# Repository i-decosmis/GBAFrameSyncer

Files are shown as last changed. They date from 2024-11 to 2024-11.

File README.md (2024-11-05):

# GBAFrameSyncer

<div align="center">
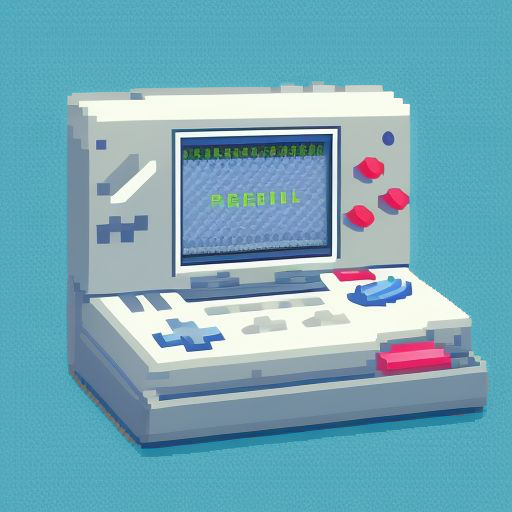
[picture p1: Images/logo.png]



</div>

# Introduction 🎮⏳
This project aims to automate the RNG manipulation process, commonly used on consoles like the Game Boy Advance. This technique, for instance, is used to [obtain shiny Pokémon in games like Pokémon Emerald](https://www.youtube.com/watch?v=pciQkasUJ7g).

Currently, the main issue with this method is that the user must manually press the console buttons to try to reach the desired frame. This process can become lengthy and frustrating, especially when aiming for advanced frames that require long waiting times; if the correct frame isn’t reached, all the waiting time is lost.

With the proposed system, we will physically modify the console to allow Arduino to automatically manage the inputs on the Game Boy Advance, precisely selecting the desired frame based on a preset timer.

# Introduzione 🎮⏳
Questo progetto è volto ad automatizzare il processo di manipolazione dell’RNG, comunemente utilizzato su console come il Game Boy Advance. Questa tecnica, ad esempio, viene sfruttata per [ottenere Pokémon shiny in giochi come Pokémon Smeraldo](https://www.youtube.com/watch?v=pciQkasUJ7g).

Attualmente, il problema principale di questo metodo è che l'utente deve premere manualmente i pulsanti sulla console per cercare di raggiungere il frame desiderato. Questo processo può diventare lungo e frustrante, specialmente quando si punta a frame avanzati che richiedono attese prolungate; se poi non si riesce a selezionare il frame corretto, tutto il tempo trascorso in attesa viene perso.

Con il sistema proposto, modificheremo fisicamente la console per consentire ad Arduino di gestire automaticamente gli input sul Game Boy Advance, selezionando con precisione il frame desiderato in base a un timer preimpostato.

- [English version](Guide/en/README.md)
- [Versione italiana](Guide/it/README.md)

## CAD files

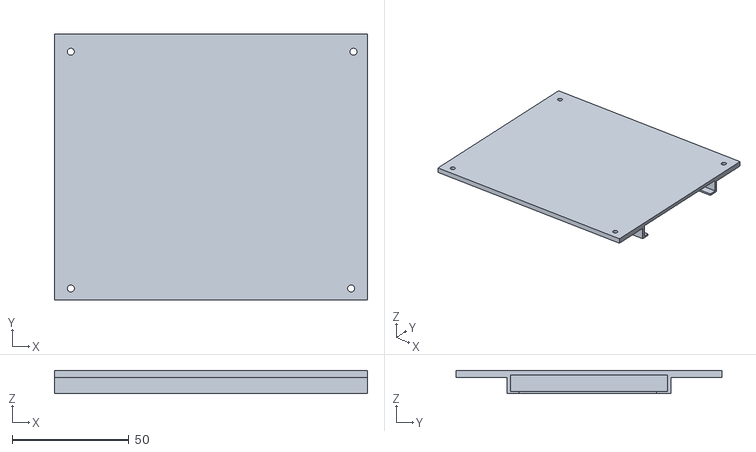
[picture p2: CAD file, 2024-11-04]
3dFiles/lid.stl
134.0 x 114.0 x 10.0

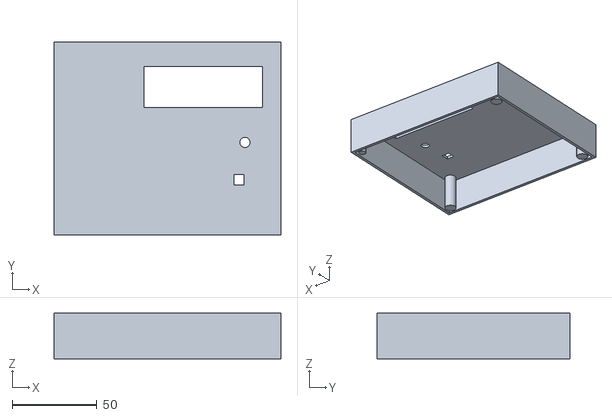
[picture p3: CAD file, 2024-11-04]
3dFiles/case.stl
134.0 x 114.0 x 27.0

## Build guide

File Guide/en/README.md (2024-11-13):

# Responsibility ⚠️
This guide is provided for informational purposes and has been compiled with the utmost care. However, the author accepts no responsibility for any damages, malfunctions, or failures arising from the use of the information contained herein. Users are advised to proceed with caution and use their judgment and expertise. Using this guide is entirely at your own risk.

Following this guide will irreversibly modify the shell.

I recommend following the [video](https://www.youtube.com/watch?v=LYbvFizmgOc) for all the details and using this guide for code references or for an overview of the project.

# System Usage Guide 📝
## Upload the Code 🔄
* Open the Arduino IDE.
* Upload the selected code from the available versions on Arduino (further details below).

## Start 🚀
* Power the system through the USB-C port.
* Connect the system connector to the one installed on the GBA.
* Turn on the system.

## If using the version with LCD display 🖥️
* Adjust brightness by clicking the button.
* Once you’ve selected the desired brightness, hold the button down for more than 2 seconds and then release it.
* Use the potentiometer to set the timer. The potentiometer can increase or decrease the timer by one, ten, one hundred, or one thousand units, depending on the direction of rotation.
* After setting the timer, click the button.
* The GBA will automatically restart after 5 seconds.
* When the set time is up, Arduino will press the A button on the GBA.
* Reset the system by powering off and on Arduino.

## If using the version without LCD display 👀
This version requires a PC.
* Open the `NoDisplayMaxOptimized.ino` code with Arduino IDE.
* In line 2, change the `value` field to set the desired time for the timer.
* Connect Arduino to the GBA via the connector.
* Connect Arduino to the PC.
* If off, turn Arduino on via the button.
* Upload the code to Arduino.
* Arduino will automatically restart the GBA after 5 seconds.
* When the time set in `value` expires, Arduino will press the A button.
* Reset the system by powering off and on Arduino.

## Differences Between the three Code Versions 🆚
Three code versions are available:
* `CompleteCode.ino`: Includes all features, such as the LCD panel and real-time timer progress updates.
* `OptimizedCode.ino`: Includes the LCD panel but is optimized to reduce timer lag by dedicating all resources to timer control, without calculating progress percentage.
* `NoDisplay.ino`: Excludes the LCD display, potentiometer, and button, requiring a PC for use.

`OptimizedCode.ino` and `NoDisplay.ino` provide the same performance.
In `CompleteCode.ino`, performance is still considered, as the remaining percentage is updated only once every 5 seconds, and only if there are at least 10 seconds left, allowing for the best possible precision.

## Considerations about the code
The system must be restarted every time after the timer because I've used the `micros` function that overflow after around 70 minutes. To avoid problems I choos this approach

# Details 🔎
This document does NOT cover RNG manipulation techniques on GBA but presents a system to automate the RNG manipulation process on GBA.  
The goal is to create a system usable without a PC. Refer to the accompanying video for additional step-by-step details.

Here is the translation in English:

# Requirements ✅
* Soldering iron
* Hot glue
* A GBA
* 3D printer
* [Arduino Nano](https://www.amazon.it/dp/B0CWH4P152)
* 4 [optocouplers](https://www.amazon.it/dp/B07X46SYQT)
* [220, 1k, 10k ohm resistors](https://www.amazon.it/dp/B0B8CQ9FYC)
* [Breadboard](https://www.amazon.it/dp/B078HV79XX)
* [100 microF capacitor](https://amzn.eu/d/5ATUCtE)
* [Small electric wires](https://amzn.eu/d/4wbI2sM)
* [Potentiometer](https://www.amazon.it/dp/B09LLVJ4WK)
* [Buttons](https://www.amazon.it/dp/B082DBBPGC)
* [Switches](https://www.amazon.it/dp/B0BTM3WQXN)
* [USB-C connectors](https://www.amazon.it/dp/B0DFPV1V35)
* [USB-C plug](https://www.amazon.it/dp/B0D5PVDJLX)
* [16x02 LCD](https://www.amazon.it/dp/B082166FCL)
* [5-pin connector](https://www.amazon.it/dp/B0C9C2NSYC)
* [Heat shrink tubing](https://amzn.eu/d/3FiaBTP)

# Guide 🧭
## Modifying the GBA 🛠️
In this example, a Game Boy Advance SP is used.
I recommend following the [video](https://www.youtube.com/watch?v=LYbvFizmgOc) for all the details and using this guide for code references or for an overview of the project.

### Step One 1️⃣
Solder thin wires onto the pins highlighted in the image. [Video for details](https://youtu.be/LYbvFizmgOc?si=4nlweEES0AOSoRyo&t=297)

gbamother

### Step Two 2️⃣
Drill the shell.
You can use a pre-modified shell with a hole on the right side.

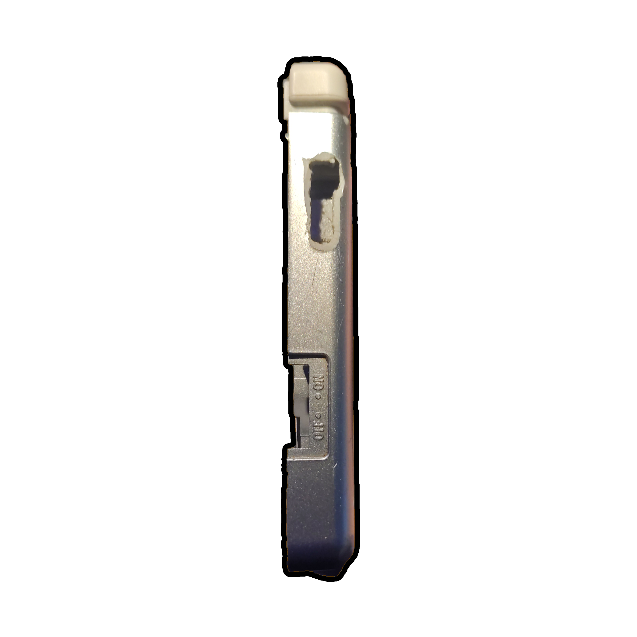
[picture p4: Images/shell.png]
shell


The goal is to guide the newly soldered wires out of the shell. Choose the best spot according to your needs. [Video for details](https://youtu.be/LYbvFizmgOc?si=U2tAdF9u9yge6Rqz&t=344)

### Step Three 3️⃣
Reassemble the GBA SP. [Video for details](https://youtu.be/LYbvFizmgOc?si=co-ZYWx3jPB3q41W&t=473)

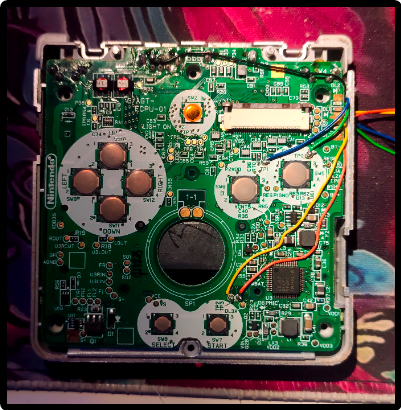
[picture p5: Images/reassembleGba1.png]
reassemble1


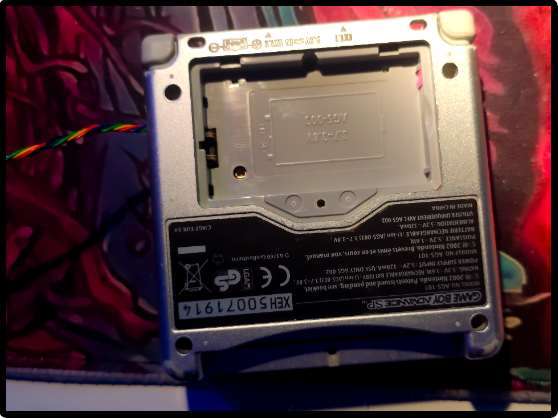
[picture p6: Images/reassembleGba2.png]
reassemble2


## Building the Circuit ⚡
Follow the wiring diagram to create the circuit. [Video for details](https://youtu.be/LYbvFizmgOc?si=nMbl5dTbhvIPqXga&t=812)

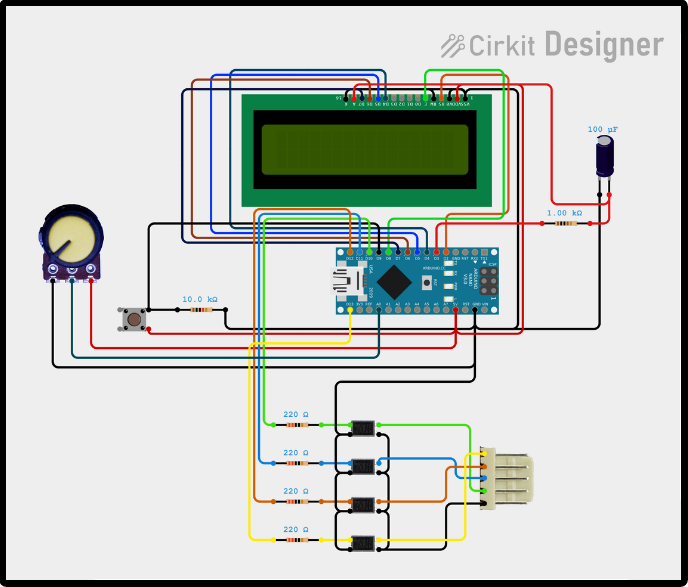
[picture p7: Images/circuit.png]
circuit


A USB-C extension with a button is recommended to interrupt power, allowing Arduino to be powered and reprogrammed even after assembly. [Video for details](https://youtu.be/LYbvFizmgOc?si=zW4mFCezqnHYHnvz&t=1474)
Many portable batteries stop charging if the load is too low, so a resistor in parallel to Arduino is added to enable power from portable batteries. There are more efficient solutions, but this is the simplest and most practical. [Video for details](https://youtu.be/LYbvFizmgOc?si=GJT893XRXDBKK_TV&t=1539)

### Circuit without LCD Display, Potentiometer, and Button ⚡👀
Use the `NoDisplay.ino` code with this wiring diagram.

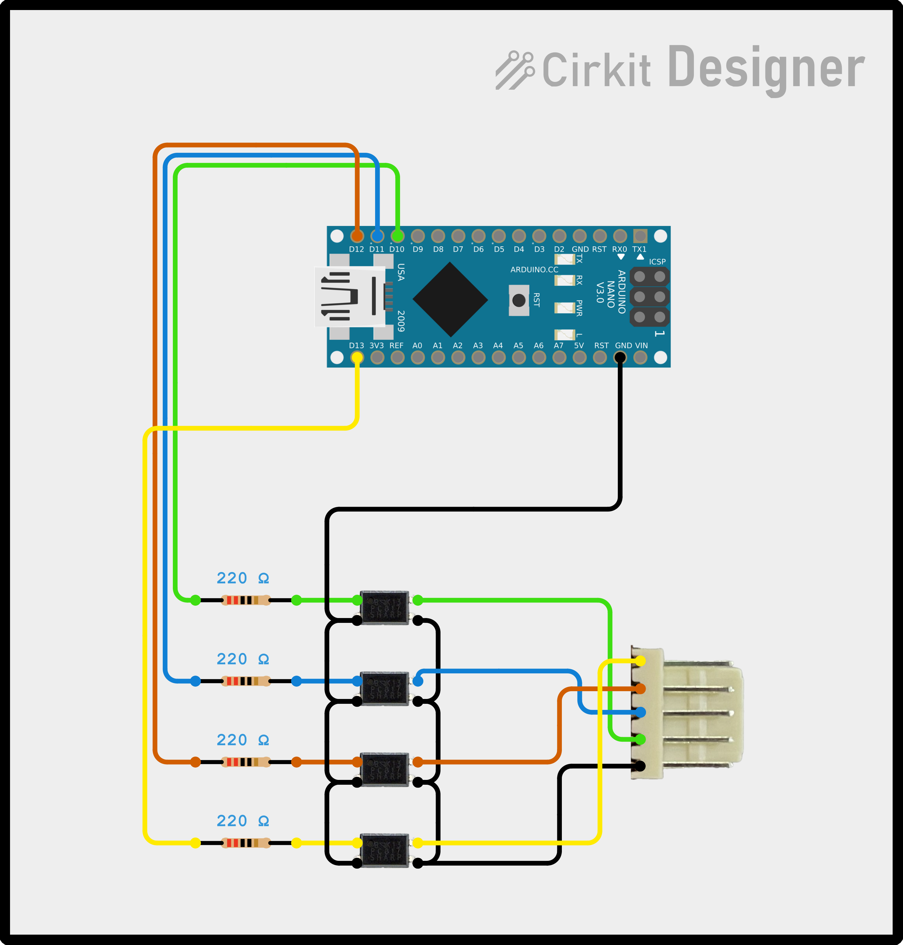
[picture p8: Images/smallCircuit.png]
circuit


## Printing and Assembling the Enclosure 📐
This was my first experience designing and printing an enclosure for a circuit, and there is certainly room for more compactness and optimization.
[This enclosure](../../3dFiles/) is designed for the complete version of the circuit.
Print the 3D file, choose points for drilling holes for the button, input USB-C port, and GBA connector.
Assemble the circuit in the enclosure. [Video for details](https://youtu.be/LYbvFizmgOc?si=2Pv3CYcU8y9FNbQ5)

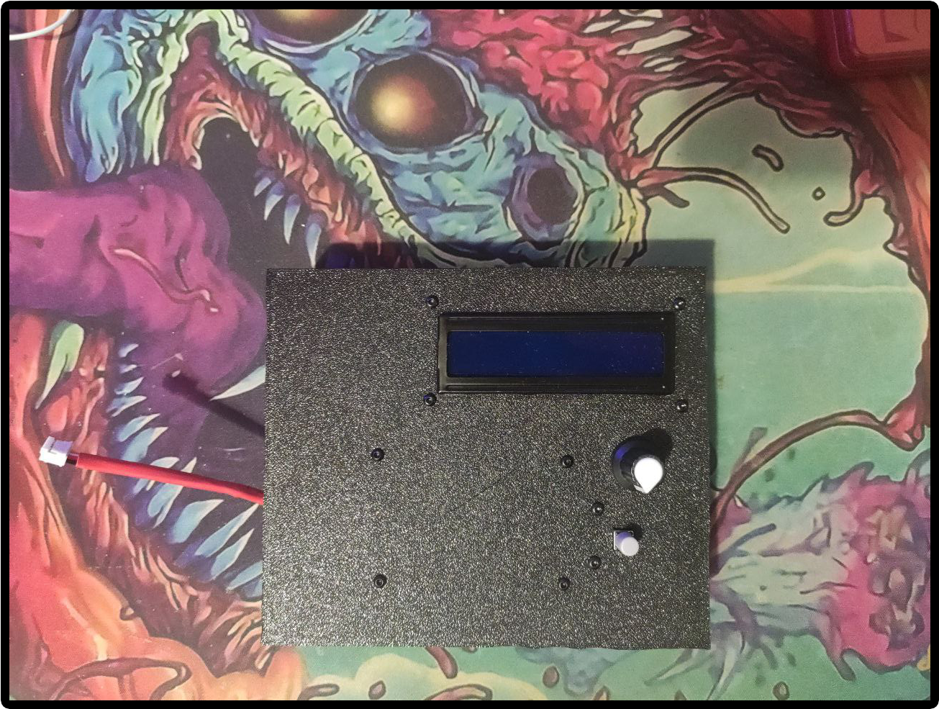
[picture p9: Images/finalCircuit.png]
circuit


There is a section under the cover where a portable battery can be placed. This choice allows the system to be used without a PC or electrical outlet.

circuit

## System Testing 🔬
A system test is available here.

## Physical Error Evaluation 📊
After multiple tests, the maximum number of attempts to calculate physical error in delay was found to be 4. In most cases, no more than 3 attempts were needed.
This error arises from the way Arduino measures time: its ceramic chip is sensitive to temperature changes, causing slight precision fluctuations.
A possible solution could be the use of dedicated timer modules, less affected by temperature.
Also, consider the possible delay of optocouplers and connections.

# Issues 🆘
No issues encountered so far.

# License 🛂
This project is licensed under the **GNU General Public License v3.0**. You are free to use, modify, and distribute this code under the following conditions:

1. **Attribution**: If you use this code as a basis for your project or create derivative works, please credit me by including my name (Ivan De Cosmis) in the project documentation, README, or other relevant materials.

2. **Share Alike**: Any derivative works based on this project must be licensed under GPLv3, ensuring future users benefit from your modifications.

3. **Commercial Use**: If you intend to use this project or derivatives for commercial purposes, contact me to discuss proper attribution and any agreements.

For more details, see the full text of the **GNU General Public License v3.0** [here](https://www.gnu.org/licenses/gpl-3.0.html).

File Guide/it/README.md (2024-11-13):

# Responsabilità ⚠️
Questa guida è fornita a scopo informativo e redatta con la massima cura possibile. Tuttavia, l'autore non si assume alcuna responsabilità per eventuali danni, guasti o malfunzionamenti derivanti dall'uso delle informazioni qui contenute. L'utente è invitato a procedere con cautela e a utilizzare il proprio giudizio e competenza. L'uso di questa guida è interamente a proprio rischio.

Seguire questa guida modifica in modo irreversibile la shell.

Si consiglia di seguire il [video](https://www.youtube.com/watch?v=Go9e5wqC74Q) per tutti i dettagli e usare questa guida per riferimenti al codice o per una visione generale del progetto.

# Guida all'utilizzo del sistema 📝
## Caricare il codice 🔄
* Aprire Arduino IDE.
* Caricare il codice scelto tra le versioni disponibili su Arduino (approfondimenti piú in basso).

## Inizio 🚀
* Alimentare il sistema tramite la porta USB-C.
* Collegare il connettore del sistema a quello installato sul GBA.
* Accendere il sistema.

## Se si utilizza la versione con display LCD 🖥️
* Regolare la luminosità cliccando il pulsante.
* Dopo aver scelto la luminosità preferita, tenere premuto il pulsante per più di 2 secondi e poi rilasciarlo.
* Usare il potenziometro per impostare il timer. Il potenziometro può variare il tempo aggiungendo o sottraendo al timer una, dieci, cento o mille unità, a seconda della rotazione verso destra o sinistra.
* Dopo aver impostato il timer, cliccare il pulsante.
* Dopo 5 secondi il GBA si riavvierà automaticamente.
* Al termine del tempo impostato, Arduino premerà il tasto A sul GBA.
* Resetta il sistema accendendo e spegnendo Arduino.

## Se si utilizza la versione senza display LCD 👀
Questa versione richiede l'uso del PC.
* Aprire il codice `NoDisplayMaxOptimized.ino` con Arduino IDE.
* Alla riga 2, modificare il valore di `value` con il tempo desiderato per il timer.
* Collegare Arduino al GBA tramite il connettore.
* Collegare Arduino al PC.
* Accendere Arduino tramite il pulsante, se spento.
* Caricare il codice su Arduino.
* Dopo 5 secondi Arduino riavvierà automaticamente il GBA.
* Al termine del tempo impostato tramite `value`, Arduino premerà il tasto A.
* Resetta il sistema accendendo e spegnendo Arduino.

## Considerazioni sul codice
Il sistema deve essere riavviato ogni volta dopo il timer perché ho utilizzato la funzione `micros` che va in overflow dopo circa 70 minuti. Per evitare problemi, ho scelto questo approccio.

## Differenze tra le tre versioni di codice 🆚
Sono disponibili tre versioni del codice:
* `CompleteCode.ino`: Include tutte le funzionalità, ovvero il pannello LCD e l'aggiornamento in tempo reale della percentuale di avanzamento del timer.
* `OptimizedCode.ino`: Include il pannello LCD, ma è ottimizzato per ridurre gli sfasamenti del timer, poiché non calcola la percentuale di avanzamento e dedica tutte le risorse al controllo del timer.
* `NoDisplay.ino`: Esclude il display LCD, il potenziometro e il pulsante, richiedendo un PC per l'uso.

`OptimizedCode.ino` e `NoDisplay.ino` offrono le stesse prestazioni.
Ecco una versione rivista:
Nel file `CompleteCode.ino` le prestazioni sono comunque considerate, poiché l'aggiornamento della percentuale rimanente viene calcolato solo una volta ogni 5 secondi, e solo se mancano almeno 10 secondi al termine, permettendo di essere più precisi possibile.

# Dettagli 🔎
In questo documento NON verranno illustrate le tecniche di manipolazione RNG su GBA, ma verrà presentato un sistema per automatizzare il processo di manipolazione RNG su GBA. 
L'obiettivo è ottenere un sistema utilizzabile senza PC. Si consiglia di consultare il video di accompagnamento per ulteriori dettagli sui passaggi.

# Requisiti ✅
* Saldatore
* Colla a caldo
* Un GBA
* Stampante 3D
* [Arduino Nano](https://www.amazon.it/dp/B0CWH4P152)
* 4 [fotoaccoppiatori](https://www.amazon.it/dp/B07X46SYQT)
* [Resistori da 220, 1k, 10k ohm](https://www.amazon.it/dp/B0B8CQ9FYC)
* [Breadboard](https://www.amazon.it/dp/B078HV79XX)
* [Condensatore da 100 microF](https://amzn.eu/d/5ATUCtE)
* [Piccoli fili elettrici](https://amzn.eu/d/4wbI2sM)
* [Potenziometro](https://www.amazon.it/dp/B09LLVJ4WK)
* [Pulsanti](https://www.amazon.it/dp/B082DBBPGC)
* [Interruttori](https://www.amazon.it/dp/B0BTM3WQXN)
* [Connettori USB-C](https://www.amazon.it/dp/B0DFPV1V35)
* [Plug USB-C](https://www.amazon.it/dp/B0D5PVDJLX)
* [LCD 16x02](https://www.amazon.it/dp/B082166FCL)
* [Connettore a 5 pin](https://www.amazon.it/dp/B0C9C2NSYC)
* [Guaina termorestringente](https://amzn.eu/d/3FiaBTP)

# Guida 🧭
## Modifica del GBA 🛠️
In questo esempio, viene utilizzato un Game Boy Advance SP.
Si consiglia di seguire il [video](https://www.youtube.com/watch?v=Go9e5wqC74Q) per tutti i dettagli e usare questa guida per riferimenti al codice o per una visione generale del progetto.

### Primo Passo 1️⃣
Saldare dei fili sottili sui pin evidenziati nell'immagine. [Video per dettagli](https://youtu.be/Go9e5wqC74Q?si=0ailfBb1nve0NTEq&t=297)

gbamother

### Secondo Passo 2️⃣
Forare la shell.
È possibile utilizzare una shell già modificata, con un foro sul lato destro.

shell

L'obiettivo è far uscire i fili appena saldati dalla shell. È possibile scegliere il punto migliore in base alle proprie esigenze. [Video per dettagli](https://youtu.be/Go9e5wqC74Q?si=EwM6Wy2F0S_5Iixp&t=343)

### Terzo Passo 3️⃣
Riassemblare il GBA SP. [Video per dettagli](https://youtu.be/Go9e5wqC74Q?si=ZEf_0g8SJ7sQub_D&t=473)

reassemble1

reassemble2

## Creazione del circuito ⚡
Seguire lo schema elettrico per creare il circuito. [Video per dettagli](https://youtu.be/Go9e5wqC74Q?si=ReuIE5ckI4RUfrOY&t=811)

circuit

È consigliato l'uso di un'estensione USB-C con un pulsante per interrompere l'alimentazione, permettendo di alimentare e riprogrammare Arduino anche dopo l'assemblaggio. [Video per dettagli](https://youtu.be/Go9e5wqC74Q?si=RNg4reDLDHr8Mhwt&t=1474)
Molte batterie portatili smettono di caricare se il carico è troppo basso; per questo motivo è inserita una resistenza in parallelo ad Arduino, consentendo l’alimentazione anche da batterie portatili. Esistono soluzioni più efficienti, ma questa è risultata la più immediata e pratica. [Video per dettagli](https://youtu.be/Go9e5wqC74Q?si=IZFsZYNZBOl73R__&t=1535)

### Circuito senza display LCD, potenziometro e pulsante ⚡👀
Utilizzare il codice `NoDisplay.ino` con questo schema.

circuit

## Stampa e assemblaggio della scocca 📐
Questa è stata la mia prima esperienza nella progettazione e stampa di una scocca per un circuito, e c'è sicuramente margine per una maggiore compattezza e ottimizzazione.
[Questa scocca](../../3dFiles/) è progettata per la versione completa del circuito.
Stampare il file 3D, scegliere i punti in cui praticare i fori per il pulsante, la presa USB-C di ingresso e il connettore per il GBA.
Assemblare il circuito nella scocca. [Video per dettagli](https://youtu.be/Go9e5wqC74Q?si=8puFOmgHlYpe24ta&t=1650)

circuit

Sotto il coperchio è presente una sezione in cui è possibile inserire una batteria portatile. Questa scelta consente di utilizzare il sistema senza PC o presa elettrica.

circuit

## Test del sistema 🔬
È disponibile un test del sistema qui.

## Valutazione dell'errore fisico 📊
Dopo diversi test, il numero massimo di tentativi per calcolare l'errore fisico nel delay è risultato essere 4. Nella maggior parte dei casi non è stato necessario più di 3 tentativi.
Questo errore deriva dal metodo con cui Arduino misura il tempo: il suo chip in ceramica è sensibile alle variazioni di temperatura, causando lievi oscillazioni di precisione.
Una possibile soluzione potrebbe essere l'uso di moduli dedicati al timer, meno influenzati dalla temperatura.
Occorre inoltre considerare l'eventuale delay dei fotoaccoppiatori e dei collegamenti.

# Problemi 🆘
Nessun problema riscontrato finora.

# Licenza 🛂
Questo progetto è concesso sotto licenza **GNU General Public License v3.0**. Sei libero di usare, modificare e distribuire questo codice alle seguenti condizioni:

1. **Attribuzione**: Se usi questo codice come base per il tuo progetto o crei opere derivate, ti preghiamo di dare credito includendo il mio nome (Ivan De Cosmis) nella documentazione del progetto, README o altri materiali pertinenti.

2. **Condivisione allo stesso modo**: Qualsiasi lavoro derivato basato su questo progetto deve essere concesso in licenza sotto GPLv3, per garantire che gli utenti futuri possano beneficiare delle tue modifiche.

3. **Uso commerciale**: Se intendi usare questo progetto o derivati per scopi commerciali, contattami per discutere la corretta attribuzione e eventuali accordi.

Per maggiori dettagli, consulta il testo completo della **GNU General Public License v3.0** [qui](https://www.gnu.org/licenses/gpl-3.0.html).

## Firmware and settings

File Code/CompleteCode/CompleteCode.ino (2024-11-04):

// Include LCD library
#include <LiquidCrystal.h>

// Setting up LCD 16x02
const int RS = 2, E = 8, D4 = 4, D5 = 5, D6 = 6, D7 = 7;
LiquidCrystal lcd(RS, E, D4, D5, D6, D7);
// Setting up brightness control pin and variables
// Brightness output pin
const int brightnessPwmPin = 3;
// Brightness button pin control
const int button = 9;
// Brightness values
int brightnessValues[] = {102, 153, 204, 255 };
int brightnessIndex = 2;
// Brightness button state
bool buttonState = LOW;
bool lastButtonState = LOW;

// Setting up potentiometer
// Potentiomenter Pin
const int potPin = A0;
// Setting up variables to avoid bouncing
unsigned long previousMillis = 0;
unsigned long interval = 100;
// Setting up sensibility values
const int range = 102;
const int rangeValues[] = { range * 1, range * 2, range * 3, range * 4 };

// Setting up GBA pins
const int A = 10;
const int B = 11;
const int Start = 12;
const int Select = 13;
// Setting up GBA timer
// Time in milliseconds
unsigned long long currentTime = 0;
unsigned long long checkPercentage = 0;
unsigned long timeStart = 0;
unsigned long long value = 0;
long selectedValue = 0;
const long maxValue = 2147483647;
const long minValue = 0;
int percentage = 0;


void setup() {
  // Set up the LCD's dimensions
  lcd.begin(16, 2);
  // Setting brightness pin control
  pinMode(brightnessPwmPin, OUTPUT);
  pinMode(button, INPUT);
  // Setting up GBA pins
  // Pin A
  pinMode(A, OUTPUT);
  digitalWrite(A, LOW);
  // Pin B
  pinMode(B, OUTPUT);
  digitalWrite(B, LOW);
  // Pin Start
  pinMode(Start, OUTPUT);
  digitalWrite(Start, LOW);
  // Pin Select
  pinMode(Select, OUTPUT);
  digitalWrite(Select, LOW);
  // Pin potentiometer
  pinMode(potPin, INPUT);
  analogWrite(brightnessPwmPin, brightnessValues[brightnessIndex]);

  // Initializing LCD for brightness setting
  clearAndWriteFirstRow("Brightness:");
  clearAndWriteSecondRow(brightnessIndex);
  bool setBrightness = false;
  bool setTimer = false;
  // Variable to measure time since start pressing
  unsigned long pressStartTime = 0;

  while (!setBrightness) {
    // Read button state
    buttonState = digitalRead(button);
    if (buttonState == HIGH) {  // If button is pressed
      if (lastButtonState == LOW) {
        // Start counting time
        pressStartTime = millis();
      } else if (millis() - pressStartTime >= 2000) {  // Check if button is pressed for 2 seconds
        // End cicle
        setBrightness = true;
        bool exit = false;
        while (!exit){
          buttonState = digitalRead(button);
          if (buttonState == LOW){
            exit = true;
          }
        }
      }
    } else {  // Button released
      if (lastButtonState == HIGH && millis() - pressStartTime < 2000) {
        // If button is pressed and then released before 2 seconds
        // Next value
        brightnessIndex = (brightnessIndex + 1) % 4;
        // Set new value
        analogWrite(brightnessPwmPin, brightnessValues[brightnessIndex]);
        // Update LCD
        clearAndWriteSecondRow(brightnessIndex);
        // Debounce
        delay(50);
      }
    }
    // Update button state
    lastButtonState = buttonState;
  }
  // Preparing LCD
  clearAndWriteFirstRow("Insert Timer:");
  clearSecondRow();
  while (!setTimer) {
    buttonState = digitalRead(button);
    if (buttonState == HIGH) {
      setTimer = true;
    } else {
      // Read potentiometer
      int potValue = analogRead(potPin);

      // Calculate the distance from the center of the potentiometer (half of 1023 is 512)
      int distanceFromCenter = potValue - 512;

      // Set the speed based on the distance from the center
      // The greater the distance, the shorter the interval, and thus the faster the speed
      interval = map(abs(distanceFromCenter), 0, 512, 1000, 10);  // 10 ms is the fastest, 1000 ms is the slowest

      // Check if enough time has passed
      unsigned long currentMillis = millis();
      if (currentMillis - previousMillis >= interval) {
        // Save the current time
        previousMillis = currentMillis;

        // If the potentiometer is turned to the right (value above 512), increase the value
        if (distanceFromCenter > 0) {
          if (abs(distanceFromCenter) >= rangeValues[3]) {
            selectedValue += 1000;
          } else if (abs(distanceFromCenter) >= rangeValues[2]) {
            selectedValue += 100;
          } else if (abs(distanceFromCenter) >= rangeValues[1]) {
            selectedValue += 10;
          } else if (abs(distanceFromCenter) >= rangeValues[0]) {
            selectedValue += 1;
          }
          if (selectedValue > maxValue) selectedValue = maxValue;  // Limit to the maximum value
        }
        // If the potentiometer is turned to the left (value below 512), decrease the value
        else if (distanceFromCenter < 0) {
          if (abs(distanceFromCenter) >= rangeValues[3]) {
            selectedValue -= 1000;
          } else if (abs(distanceFromCenter) >= rangeValues[2]) {
            selectedValue -= 100;
          } else if (abs(distanceFromCenter) >= rangeValues[1]) {
            selectedValue -= 10;
          } else if (abs(distanceFromCenter) >= rangeValues[0]) {
            selectedValue -= 1;
          }
          if (selectedValue < minValue) selectedValue = minValue;
        }
        clearAndWriteSecondRow(selectedValue);
      }
    }
  }
  value = static_cast<unsigned long long>(selectedValue);
  clearAndWriteFirstRow("Resetting...");
  unsigned long startTime = millis();
  while (millis() - startTime < 5000UL) {
    // Wait 5 seconds without using delay()
  }
  digitalWrite(A, HIGH);
  digitalWrite(B, HIGH);
  digitalWrite(Start, HIGH);
  digitalWrite(Select, HIGH);
  delayMicroseconds(15000);
  digitalWrite(A, LOW);
  digitalWrite(B, LOW);
  digitalWrite(Start, LOW);
  digitalWrite(Select, LOW);
  timeStart = micros();
  checkPercentage = timeStart;
  value = value * 1000;
  clearAndWriteFirstRow("Waiting...");
  clearSecondRow();
}

void loop() {
  currentTime = micros();
  // Enter if timer expired
  if ((currentTime - timeStart) >= value) { 
      digitalWrite(A, HIGH);
      delayMicroseconds(15000);
      digitalWrite(A, LOW);
      clearAndWriteFirstRow("Done!");
      clearSecondRow();
    while(1){
      // Wait for reset
    }
  }
  // To avoid to lose precision, update every 5 seconds, only if the remaining time is more than 10 seconds
  if ((value - (currentTime - timeStart)) > 10000000UL){
    if (currentTime - checkPercentage > 5000000UL) {
      percentage = (((currentTime - timeStart) * 100) / value);
      clearAndWriteSecondRow(String(percentage)+"%");
      checkPercentage = micros();
    }  
  }
}


void clearAndWriteFirstRow(String text){
  lcd.setCursor(0, 0);
  lcd.print("                ");
  lcd.setCursor(0, 0); 
  lcd.print(text);
}

void clearAndWriteSecondRow(String text){
  lcd.setCursor(0, 1);
  lcd.print("                ");
  lcd.setCursor(0, 1); 
  lcd.print(text);
}

void clearAndWriteFirstRow(long number){
  lcd.setCursor(0, 0);
  lcd.print("                ");
  lcd.setCursor(0, 0); 
  lcd.print(number);
}

void clearAndWriteSecondRow(long number){
  lcd.setCursor(0, 1);
  lcd.print("                ");
  lcd.setCursor(0, 1); 
  lcd.print(number);
}

void clearFirstRow(){
  lcd.setCursor(0, 0);
  lcd.print("                ");
}

void clearSecondRow(){
  lcd.setCursor(0, 1);
  lcd.print("                ");
}

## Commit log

2024-10-30 Added arduino code
2024-11-04 Completed code, added README
    [case.stl, lid.stl]
